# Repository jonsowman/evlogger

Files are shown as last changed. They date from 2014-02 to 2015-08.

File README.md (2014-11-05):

Electric Vehicle Datalogger
===========================

This project uses an MSP430 (specifically, the MSP430F5529) to log data from
various channels to be used on an electric vehicle. This project is designed
for use on the MSP-EXP430F5529LP experimentation board which is available from
Texas Instruments.  

Documentation at http://jonsowman.github.com/evlogger.  

Released into the public domain by Jon Sowman, 2014.  

[Get in touch](mailto:j.sowman@soton.ac.uk)

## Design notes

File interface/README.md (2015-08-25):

# Interface between EVLogger and sensors/vehicle

Logger samples ADC channels:  

* 6  - P6.6
* 7  - P6.7
* 12 - P7.0
* 13 - P7.1
* 14 - P7.2
* 15 - P7.3
* 5  - User potentiometer

6 and 7 are pins 2 and 14 on Pin Header J4  
12, 13, 14, 15 are pins 2, 4, 6, 8 on Pin Header J5  

For GPS, UCA1 is available on Pin Header J4, but this is shared with the ez430
programmer and requires removing/adding jumpers.  

* 1 - VCC
* 3 - RXD
* 5 - TXD
* 13 - GND

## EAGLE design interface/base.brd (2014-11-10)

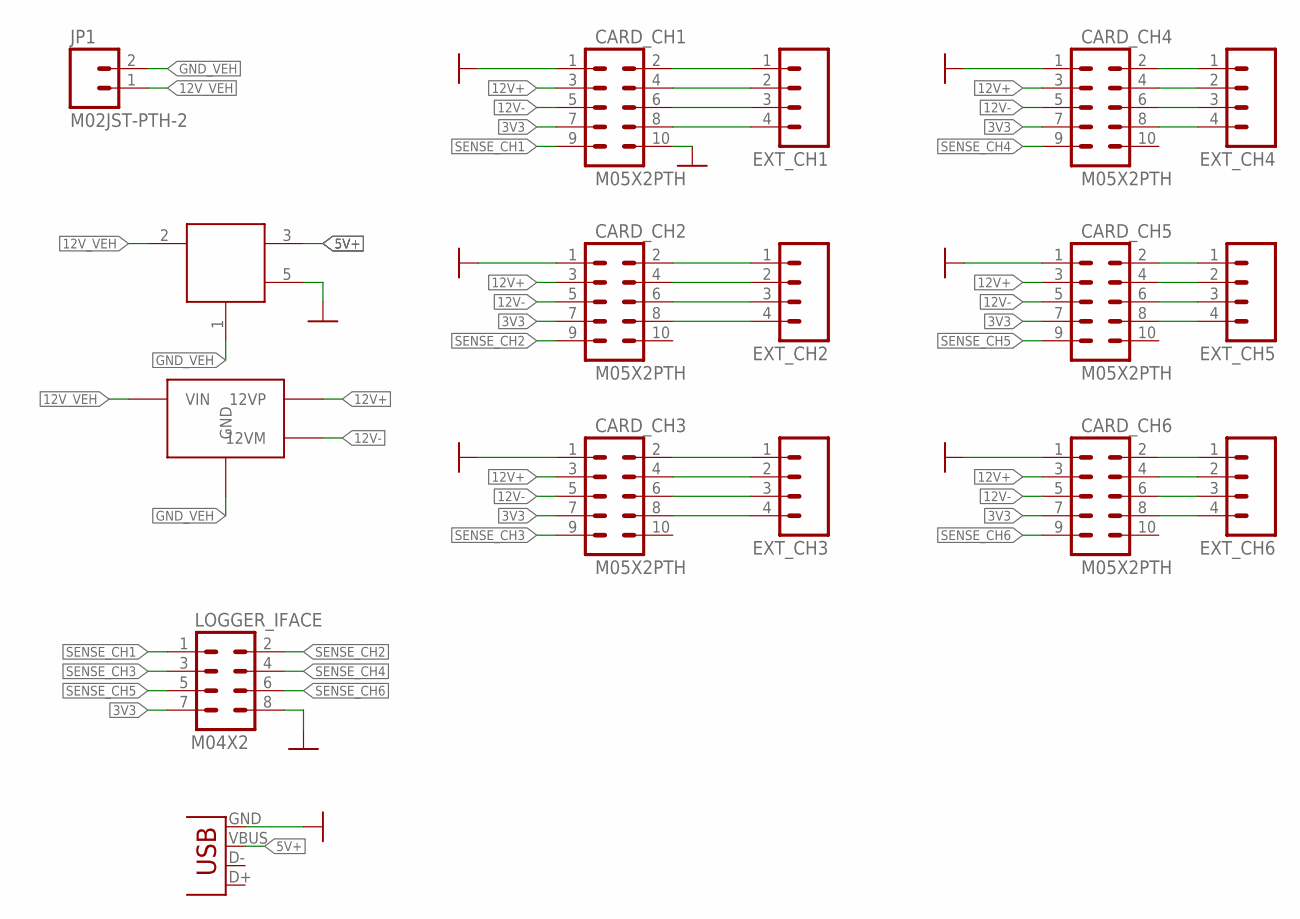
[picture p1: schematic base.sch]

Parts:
CARD_CH1, CARD_CH2, CARD_CH3, CARD_CH4, CARD_CH5, CARD_CH6: M05X2PTH; AVR_ICSP
EXT_CH1, EXT_CH2, EXT_CH3, EXT_CH4, EXT_CH5, EXT_CH6: M04PTH; 1X04
JP1: M02JST-PTH-2; JST-2-PTH
JP2: USB-A-S
LOGGER_IFACE: M04X2; 2X4
U$1: NMXS1205UC_PTH
U$2: TMR3122_12_CONV_PTH

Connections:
3V3: CARD_CH1.7, CARD_CH2.7, CARD_CH3.7, CARD_CH4.7, CARD_CH5.7, CARD_CH6.7, LOGGER_IFACE.7
5V+: JP2.VBUS, U$1.3 (5VOUT)
12V+: CARD_CH1.3, CARD_CH2.3, CARD_CH3.3, CARD_CH4.3, CARD_CH5.3, CARD_CH6.3, U$2.5 (12VP)
12V-: CARD_CH1.5, CARD_CH2.5, CARD_CH3.5, CARD_CH4.5, CARD_CH5.5, CARD_CH6.5, U$2.6 (12VM)
12V_VEH: JP1.1, U$1.2 (VIN), U$2.2 (VIN)
GND: CARD_CH1.1, CARD_CH1.10, CARD_CH2.1, CARD_CH3.1, CARD_CH4.1, CARD_CH5.1, CARD_CH6.1, JP2.GND, LOGGER_IFACE.8, U$1.5 (GNDOUT)
GND_VEH: JP1.2, U$1.1 (GND), U$2.1 (GND)
unnamed: CARD_CH1.2, EXT_CH1.1
unnamed: CARD_CH1.4, EXT_CH1.2
unnamed: CARD_CH1.6, EXT_CH1.3
unnamed: CARD_CH1.8, EXT_CH1.4
unnamed: CARD_CH2.2, EXT_CH2.1
unnamed: CARD_CH2.4, EXT_CH2.2
unnamed: CARD_CH2.6, EXT_CH2.3
unnamed: CARD_CH2.8, EXT_CH2.4
unnamed: CARD_CH3.2, EXT_CH3.1
unnamed: CARD_CH3.4, EXT_CH3.2
unnamed: CARD_CH3.6, EXT_CH3.3
unnamed: CARD_CH3.8, EXT_CH3.4
unnamed: CARD_CH4.2, EXT_CH4.1
unnamed: CARD_CH4.4, EXT_CH4.2
unnamed: CARD_CH4.6, EXT_CH4.3
unnamed: CARD_CH4.8, EXT_CH4.4
unnamed: CARD_CH5.2, EXT_CH5.1
unnamed: CARD_CH5.4, EXT_CH5.2
unnamed: CARD_CH5.6, EXT_CH5.3
unnamed: CARD_CH5.8, EXT_CH5.4
unnamed: CARD_CH6.2, EXT_CH6.1
unnamed: CARD_CH6.4, EXT_CH6.2
unnamed: CARD_CH6.6, EXT_CH6.3
unnamed: CARD_CH6.8, EXT_CH6.4
SENSE_CH1: CARD_CH1.9, LOGGER_IFACE.1
SENSE_CH2: CARD_CH2.9, LOGGER_IFACE.2
SENSE_CH3: CARD_CH3.9, LOGGER_IFACE.3
SENSE_CH4: CARD_CH4.9, LOGGER_IFACE.4
SENSE_CH5: CARD_CH5.9, LOGGER_IFACE.5
SENSE_CH6: CARD_CH6.9, LOGGER_IFACE.6

Board: 2 copper layers, 17 parts (0 on the bottom side), 37 nets, no tracks yet.

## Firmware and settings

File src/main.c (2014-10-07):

/**
 * \mainpage Electric Vehicle Datalogger
 *
 * \section intro Introduction
 * This project uses an MSP430 (specifically, the MSP430F5529) to log data from
 * various channels to be used on an electric vehicle. This project is designed
 * for use on the MSP-EXP430F5529LP experimentation board which is available
 * from Texas Instruments.
 * 
 * \section spec Specification
 * There are six analogue channels broken out on the development board, plus a
 * user potentiometer. Additionally, there is a CMA3000 3-axis accelerometer
 * which is capable of running at up to 400Hz. The analogue channels (including
 * the pot) are sampled and logged at 1kHz. The accelerometer is also logged at
 * this frequency though analysis of the output will confirm that its value
 * only changes at 400Hz.
 *
 * \section software Software Architecture
 * The software documented here is written specifically for the project, but
 * libraries and hardware abstraction layer utilities are used from various
 * sources which are documentented in the code. Licenses for these parts of the
 * code are respected and as such, copyright notices will be found in some
 * source files where they were used as the basis for the code.
 *
 * The main functionality for the datalogger is in the Logger module. The
 * overall architecture overview is that we set up a timer to interrupt at the
 * log frequency, which collects available data and puts it into a buffer ready
 * to be transferred to the SD card. It then invalidates the data and triggers
 * another conversion run such that on the next interrupt, the new data will be
 * ready.
 *
 * A software controlled RingBuffer is used to store data before it is
 * transferred to the SD card, and a full ring buffer implementation can be
 * found in the Logger module. This is generic and can be used in other
 * projects. The size of this buffer is controlled by SD_RINGBUF_LEN, and
 * should be as large as possible for best performance but should never be
 * smaller than the sector size (usually 512 bytes for FAT16).
 *
 * The peripherals are controlled by separate modules, see ADC, Accelerometer,
 * UART particularly. Documentation for how these are configured can be found
 * in the relevant source files; here it suffices to note that CPU time is
 * minimised by use of DMA in the case of the ADC and an interrupt controlled
 * finite state machine (FSM) in the case of the accelerometer. The UART is
 * principally for debugging purposes and is not set up for speed (it currently
 * busy-waits during transmits) and as such, should not be used in production
 * runs of the firmware builds.
 *
 * The onboard peripherals, perticularly the CPU core clock and system wall
 * clock timer are controlled by the System module, relevant documentation is
 * contained within.
 *
 * \section build Building the Firmware
 * A Makefile is provided to build the firmware using the GNU mspgcc toolchain.
 * Builds of this toolchain are available for Windows, OS X and Linux though on
 * Windows you will need to set an IDE up as appropriate since the Makefile
 * will not work (unless you use cygwin). To build the firmware using the
 * Makefile please change to the source directory and run $ make. Flashing the
 * device is done using mspdebug over the Spy-by-Wire interface, and can be
 * enacted by running $ make flash.  Cleaning the build directory (deleting all
 * object files, dependency list files and binaries) can be done using $ make
 * clean.
 *
 * \section author Authorship
 * Jon Sowman, University of Southampton <j.sowman@soton.ac.uk>. Please get in
 * touch with any questions or comments.
 *
 * @file main.c
 * @author Jon Sowman, University of Southampton <j.sowman@soton.ac.uk>
 * @copyright Jon Sowman 2014, All Rights Reserved
 * @addtogroup main
 * @{
 */

#include <msp430.h>
#include <msp430f5529.h>
#include <stdint.h>
#include <stdio.h>

#include "HAL_Dogs102x6.h"
#include "typedefs.h"
#include "uart.h"
#include "adc.h"
#include "system.h"
#include "logger.h"

#include "HAL_SDCard.h"
#include "ff.h"

/**
 * Kill the watchdog timer to prevent it firing, then set up the system clock
 * followed by onboard peripherals. Wait for all systems to be ready before
 * starting the datalogger.
 */
int main(void)
{
    // Stop the wdt
    WDTCTL = WDTPW | WDTHOLD;

    // Set up the system clock and any required peripherals
    sys_clock_init();
    clock_init();
    uart_init();
    Dogs102x6_init();
    Dogs102x6_backlightInit();

    // Wait for peripherals to boot
    _delay_ms(100);
 
    // Test that minicom/term is behaving
    uart_debug("Hello world");

    // Test the LCD
    Dogs102x6_setBacklight(1);
    Dogs102x6_setContrast(6);
    Dogs102x6_clearScreen();
    Dogs102x6_stringDraw(0, 0, "=== EV LOGGER ===", DOGS102x6_DRAW_INVERT);

    // Wait for periphs to boot and start logging
    logger_init();
     
    // We should never get to this point
    while(1);

    return 0;
}

/**
 * @}
 */

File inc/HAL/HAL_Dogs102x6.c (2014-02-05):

/*******************************************************************************
 *
 *  HAL_Dogs102x6.c - Driver for the DOGS 102x6 display
 *
 *  Copyright (C) 2010 Texas Instruments Incorporated - http://www.ti.com/
 *
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
 *    Redistributions of source code must retain the above copyright
 *    notice, this list of conditions and the following disclaimer.
 *
 *    Redistributions in binary form must reproduce the above copyright
 *    notice, this list of conditions and the following disclaimer in the
 *    documentation and/or other materials provided with the
 *    distribution.
 *
 *    Neither the name of Texas Instruments Incorporated nor the names of
 *    its contributors may be used to endorse or promote products derived
 *    from this software without specific prior written permission.
 *
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
 ******************************************************************************/

/***************************************************************************//**
 * @file       HAL_Dogs102x6.c
 * @addtogroup HAL_Dogs102x6
 * @{
 ******************************************************************************/
#include "msp430.h"
#include "in430.h"
#include "HAL_Dogs102x6.h"

// Macros
#ifndef abs
#    define abs(n)     (((n) < 0) ? -(n) : (n))
#endif

// For all commands, CD signal must = 0
#define SET_COLUMN_ADDRESS_MSB        0x10  //Set SRAM col. addr. before write, last 4 bits =
                                            // ca4-ca7
#define SET_COLUMN_ADDRESS_LSB        0x00  //Set SRAM col. addr. before write, last 4 bits =
                                            // ca0-ca3
#define SET_POWER_CONTROL             0x2F  //Set Power control - booster, regulator, and follower
                                            // on
#define SET_SCROLL_LINE               0x40  //Scroll image up by SL rows (SL = last 5 bits),
                                            // range:0-63
#define SET_PAGE_ADDRESS              0xB0  //Set SRAM page addr (pa = last 4 bits), range:0-8
#define SET_VLCD_RESISTOR_RATIO       0x27  //Set internal resistor ratio Rb/Ra to adjust contrast
#define SET_ELECTRONIC_VOLUME_MSB     0x81  //Set Electronic Volume "PM" to adjust contrast
#define SET_ELECTRONIC_VOLUME_LSB     0x0F  //Set Electronic Volume "PM" to adjust contrast (PM =
                                            // last 5 bits)
#define SET_ALL_PIXEL_ON              0xA4  //Disable all pixel on (last bit 1 to turn on all pixels
                                            // - does not affect memory)
#define SET_INVERSE_DISPLAY           0xA6  //Inverse display off (last bit 1 to invert display -
                                            // does not affect memory)
#define SET_DISPLAY_ENABLE            0xAF  //Enable display (exit sleep mode & restore power)
#define SET_SEG_DIRECTION             0xA1  //Mirror SEG (column) mapping (set bit0 to mirror
                                            // display)
#define SET_COM_DIRECTION             0xC8  //Mirror COM (row) mapping (set bit3 to mirror display)
#define SYSTEM_RESET                  0xE2  //Reset the system. Control regs reset, memory not
                                            // affected
#define NOP                           0xE3  //No operation
#define SET_LCD_BIAS_RATIO            0xA2  //Set voltage bias ratio (BR = bit0)
#define SET_CURSOR_UPDATE_MODE        0xE0  //Column address will increment with write operation
                                            // (but no wrap around)
#define RESET_CURSOR_UPDATE_MODE      0xEE  //Return cursor to column address from before cursor
                                            // update mode was set
#define SET_ADV_PROGRAM_CONTROL0_MSB  0xFA  //Set temp. compensation curve to -0.11%/C
#define SET_ADV_PROGRAM_CONTROL0_LSB  0x90

// Pins from MSP430 connected to LCD
#define CD              BIT6
#define CS              BIT4
#define RST             BIT7
#define BACKLT          BIT6
#define SPI_SIMO        BIT1
#define SPI_CLK         BIT3

// Ports
#define CD_RST_DIR      P5DIR
#define CD_RST_OUT      P5OUT
#define CS_BACKLT_DIR   P7DIR
#define CS_BACKLT_OUT   P7OUT
#define CS_BACKLT_SEL   P7SEL
#define SPI_SEL         P4SEL
#define SPI_DIR         P4DIR

// Font lookup table
static const uint8_t FONT6x8[] = {
    /* 6x8 font, each line is a character each byte is a one pixel wide column
     * of that character. MSB is the top pixel of the column, LSB is the bottom
     * pixel of the column. 0 = pixel off. 1 = pixel on. */
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

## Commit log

2013-10-26 Removed oscillator checking for now since I no longer care
    [main.c]
2013-10-26 First attempt at getting the UART working. It doesn't work. It's late and I'm going to sleep.
    [main.c, uart.c, uart.h]
2013-10-27 UART working but timing is a bit out, need to check oscillator
    [main.c, uart.c]
2013-11-12 UART working at 9600 baud, turns out ez430 programmer can't support higher than this.
2013-11-12 Added uart_debug to make my life a bit easier
2013-11-13 Started work on ADC but not quite working yet
2013-11-16 ADC working - I'm an idiot. See commit for details :(
2013-11-16 Timer0 set up for 1ms, system ticks counter created
2013-11-17 Added _BV() macro to typedefs, sd_init() created for setting up UCSI for SPI for SD card
2013-11-17 Fixed build issue, builds and runs, fatfs not tested yet. get_fattime() returns 0 (invalid) at the moment. Fix this please
    [main.c]
2014-01-24 Fixed SD card issue, SPI clock pol was wrong. Sigh
    [main.c, uart.c]
2014-01-24 Delay before trying to mount the card so that the SD timer functionality can sort itself out
2014-01-25 Put fast SPI back to 200kHz
2014-02-02 Included HAL bits for LCD from TI example code, with a couple of small modifications
2014-02-02 Commented SPI init stuff from the LCD driver, since it's already done in the SD card init
2014-02-02 Fixed SD card problems, buffer overflow. Made sure that doesn't happen again
    [main.c, uart.c, uart.h]
2014-02-03 Added accelerometer and display on lcd
2014-02-03 Button S1 working via interrupts
2014-02-03 Button S1 now controlling logging, TA1 setup up as logging timer
2014-02-03 Added sd_setup() prototype to logger.h header
2014-02-04 Fixed string length counting when writing to file
    [logger.c]
2014-02-04 Opening and closing log file on button press
2014-02-06 Detect and warn if no SD card inserted
2014-02-06 Swapped heartbeat and SD write LEDs round
    [logger.c]
2014-02-06 Button S1 starts and stops TA1 and writes logging on/off to lcd
2014-02-06 Debounce the switches and go back to 1024 byte SD write buffer
2014-02-06 Remove heartbeat LED so I can see SD_BUSY led
2014-02-06 Update lcd from main logger loop, too slow for interrupts. Monitor for buffer overflow
    [logger.c]
2014-02-06 A couple of cheeky macros should make the main logger loop run a bit quicker
2014-02-10 Removed function called from system clock interface since no longer used
    [logger.c, main.c]
2014-02-10 Removed redundant clock def prototypes. Updated copyright notice
2014-02-10 Switched to 25MHz core clock, using HAL layer for PMM from Ti
2014-02-12 ADC running in sequential conversion mode, need to set up DMA now
2014-02-12 DMA working for transferring ADC readings to a sample buffer
2014-02-13 Samplebuffer work started, not quite working yet
2014-02-14 Changed SampleBuffer to use all 16 bit values so that struct packing doesn't make my life hell
    [logger.c, logger.h]
2014-03-02 DMA accel working, not integrated yet, still in independent test mode
2014-03-02 just some tidying, about to attempt putting accel data into sample buffer
2014-03-02 correctly sampling accel to the sample buffer using dma interrupt
    [accel.c, accel.h, adc.c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]
2014-03-02 used a define'd value from the library for the DMA IV source
2014-03-02 Better naming, removed some unused stuff from timer accel implementation
2014-03-02 DMA src and dest in setup since they don't change
2014-03-02 DMA IFG is auto cleared by execution of the ISR
2014-03-03 Should be working DMA accel but isn't - attempt FSM based approach
2014-03-03 upgraded doxyfile and fixed warnings
    [accel.c, logger.c, uart.c]
2014-03-03 removed led testing
2014-03-03 Fixed docs in accel files
    [accel.c, accel.h]
2014-03-04 fixed typo in docs
    [main.c]
2014-03-04 print in base 10
2014-06-26 Added interfacing and signal conditioning circuits
    [evlogger_current.sch, evlogger_voltage.sch]
2014-06-26 Added transient voltage suppression diodes to op amp output
    [evlogger_current.sch, evlogger_voltage.sch]
2014-11-10 Adding interface hardware
    [base.brd, base.sch]
2015-08-25 added pinout
    [base.sch, evlogger_current.sch]

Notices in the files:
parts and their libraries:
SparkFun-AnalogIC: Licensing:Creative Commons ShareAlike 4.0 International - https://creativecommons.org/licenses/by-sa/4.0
